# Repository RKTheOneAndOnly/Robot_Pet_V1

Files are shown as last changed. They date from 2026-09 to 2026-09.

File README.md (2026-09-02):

#  Robot Pet - v1: An ESP32-CAM Face-Tracking Companion

A desktop robot pet built around a single **AI-Thinker ESP32-CAM**. It streams video to a laptop, finds a face (or any coloured object you show it), and turns its head to follow you — while an OLED display gives it a pair of animated eyes that blink, glance around, and change mood.

<p align="center">
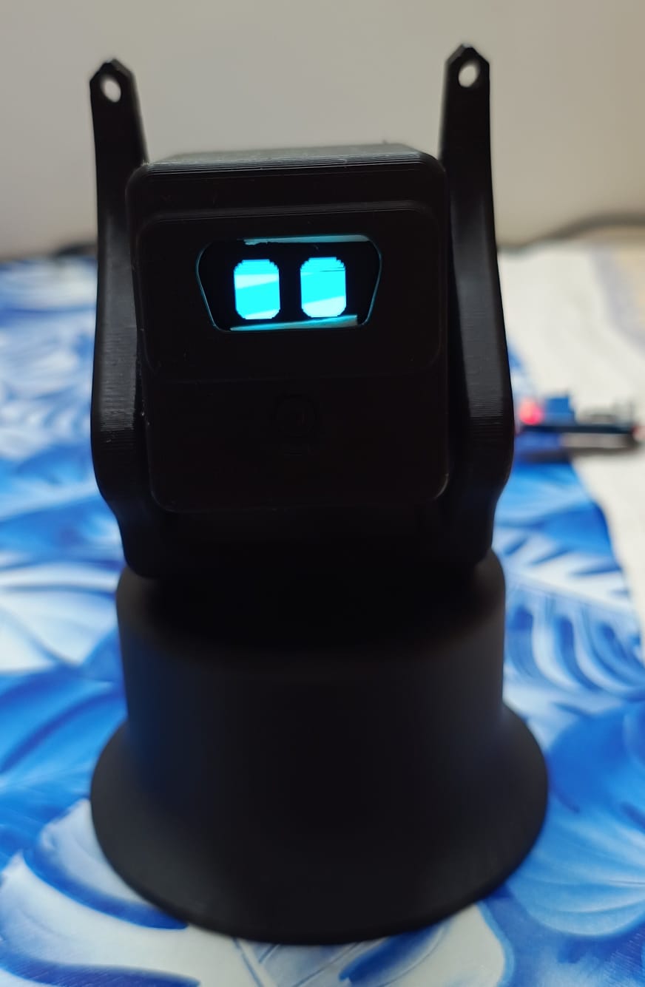
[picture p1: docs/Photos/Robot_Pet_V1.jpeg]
Robot Pet CAD - isometric view
    
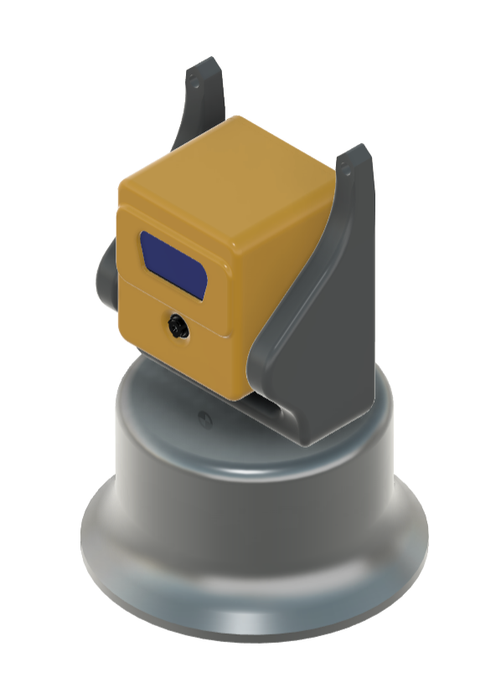
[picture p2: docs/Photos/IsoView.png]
Robot Pet CAD - isometric view
    
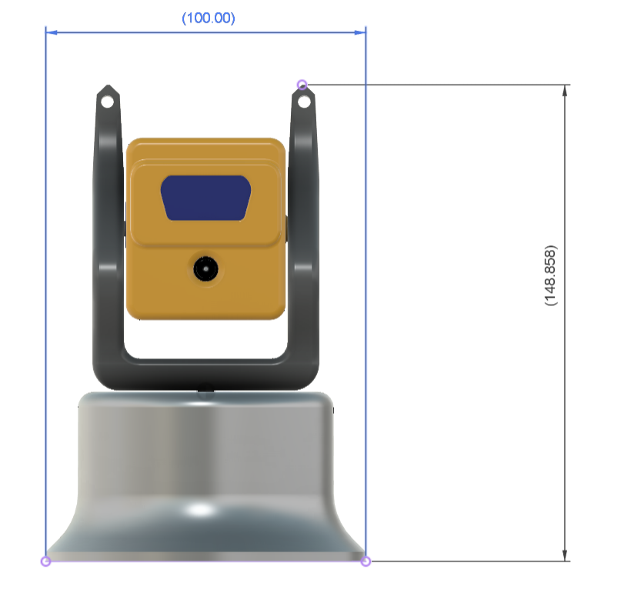
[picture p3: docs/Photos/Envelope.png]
Robot Pet motion envelope
    
</p>

The whole robot runs on one ESP32-CAM: camera, two servos, and an I²C display, with the vision work offloaded to a laptop over plain HTTP.

## 🔁 My Other Robotics Projects

- 🔗 [**Kai (ಕೈ) — 5 DOF Robotic Arm**](https://github.com/RKTheOneAndOnly/5-DOF-Robot_Arm-RK)
- 🔗 [**Robotics-Arm-Project-V01** — 3 DOF arm](https://github.com/RKTheOneAndOnly/Robotics-Arm-Project-V01)

---
## Table of Contents

1. [Introduction](#1-introduction)
2. [Components Used](#2-components-used)
3. [How It Works](#3-how-it-works)
4. [Wiring & Pin Map](#4-wiring--pin-map)
5. [Build & Flash](#5-build--flash)
6. [Running the Tracker](#6-running-the-tracker)
7. [Tuning](#7-tuning)
8. [Future Plans](#8-future-plans)
9. [Repository Structure](#9-repository-structure)
10. [Credits & Acknowledgements](#10-credits--acknowledgements)

---
## 1. Introduction

This project builds a small companion robot that:

- Streams **MJPEG video over WiFi** from an ESP32-CAM
- Tracks a **face** (Haar cascade) or any **coloured object** (HSV blob — hold up an apple)
- Drives **pan and tilt servos** to keep the target centred in frame
- Shows **animated, mood-driven eyes** on a 128×64 I²C OLED
- Is fully 3D printable, using cheap and widely available parts

The split of responsibilities is deliberate: the ESP32 handles hardware and owns all servo angles and limits, while the laptop does the computer vision. Vision never sends an absolute angle - it only says *"turn this far, this way"* - so a bug in the Python code can never drive the head into its mechanical stops.

---
## 2. Components Used

| Component | Quantity | Notes |
|---|---|---|
| AI-Thinker ESP32-CAM (OV2640) | 1 | Main controller + camera |
| SG90 micro servo | 2 | Pan and tilt |
| 1.3 " I²C OLED, 128×64 | 1 | 1.3 inch I2C OLED Display Module 4pin Blue Color |
| USB-to-TTL adapter (FTDI/CP2102)  | 1 | Flashing only — the ESP32-CAM has no USB |
| 5V power supply, ≥1A | 1 | **Separate supply for the servos** |
| 3D printed parts | 5 | STEP files in [`/cad`](./cad) |
| Jumper wires, M2/M3 screws | – | Assembly hardware |

> ⚠️ **Do not power the servos from the ESP32-CAM's 5V/3.3V pin.** Two SG90s under load will brown out the onboard regulator and reset the board mid-stream.

---
## 3. How It Works

```
   ESP32-CAM                                          Laptop (Python)
  ┌──────────────────────────────┐                  ┌──────────────────────────┐
  │  httpd :81  /stream  ────────┼── MJPEG ────────►│  reader                  │
  │  httpd :80  /control ◄───────┼── HTTP GET ──────┼─ sender                  │
  │                              │                  │                          │
  │  Display Controll            │                  │  detect using Open CV    │
  │  servos Controll             │                  └──────────────────────────┘
  └──────────────────────────────┘
```

**On the ESP32** - two independent `esp_http_server` instances, matching the layout of the Espressif `CameraWebServer` example. Port 81 serves the MJPEG stream; port 80 answers control requests. They *must* be separate servers: an httpd instance handles one request at a time, and the stream handler never returns while a viewer is connected, so a shared server would never answer a control request.

**On the laptop** - one thread reads the MJPEG stream and keeps only the newest frame, throwing away any backlog. The main loop decodes that frame, runs detection, smooths the target centroid, and computes a proportional step. A third thread issues the control request, so waiting for the ESP32 to reply never stalls tracking.

---
## 4. Wiring & Pin Map

The camera occupies almost every usable GPIO on this board — **including GPIO21/22**, the "default" ESP32 I²C pins. The OLED therefore cannot use them. These are the pins left over:

| Signal | GPIO | Notes |
|---|---|---|
| Pan servo | 2 | Strapping pin |
| Tilt servo | 13 | |
| OLED SDA | 14 | |
| OLED SCL | 15 | |

### Power

```
   5V supply ──┬── servo V+  (both servos)
               └── ESP32-CAM 5V

   GND ────────┬── servo GND (both servos)
               ├── ESP32-CAM GND      ← common ground is essential
               └── OLED GND
```

> 🔧 A loose common ground was the single hardest fault to find in this build. The servos simply do not move, the code looks wrong, and everything else keeps working perfectly. Check it first.

---
## 5. Build & Flash

Built with [PlatformIO](https://platformio.org/).

**1. Add your WiFi credentials** :

```bash
# edit include/wifi_config.h and set WIFI_SSID / WIFI_PASSWORD
```

**2. Flash the firmware**:

```bash
pio run -e esp32cam -t upload
```

> ✔️ If everything goes right the OLED shows the board's IP address once it joins WiFi.

**3. Check the camera** by opening `http://<esp32-ip>:81/stream` in a browser. This path is completely independent of the Python code, so it cleanly separates a camera/WiFi problem from a client problem.

### Servo bring-up test

A second environment builds a standalone sweep test — no camera, no WiFi, no display. Both servos sweep continuously so you can confirm the hardware works before blaming the software:

```bash
pio run -e servo_test -t upload
```

The onboard flash LED (GPIO4) blinks fast while sweeping up and slow while sweeping down, so you can confirm the sketch is running without a serial monitor attached. 
> ⚙️ **LED blinking but servos still?** That's power or wiring problem.

> Every SG90 has slightly different pulse-width endpoints. Centre both servos before assembling the head:

---
## 6. Running the Tracker

```bash
cd code/python
pip install -r requirements.txt

python track.py <esp32-ip>              # face tracking
python track.py <esp32-ip> color        # colour-blob tracking
```

| Key / action | Effect |
|---|---|
| `f` | Face mode (Haar cascade) |
| `c` | Colour mode (HSV blob) |
| **click the video** | Sample the colour under the cursor and track it |
| `q` | Quit |

>🤖 Colour mode is the easy way to test: hold up an apple, click it, and the robot follows it
---
## 7. Tuning

All tuning constants live at the top of [`code/python/track.py`](./code/python/track.py) — no reflashing needed.

| Constant | Default | Effect |
|---|---|---|
| `DEADZONE_PX` | 30 | Ignore errors smaller than this. Raise it if the head twitches on a still target. |
| `KP` | 10 | Degrees of servo movement per pixel of error. |
| `MAX_STEP_DEG` | 4 | Ceiling on any single move. |
| `SMOOTHING` | 0.5 | Centroid smoothing. 0 = raw and jumpy, 0.9 = heavy and laggy. |
| `SEND_INTERVAL_S`  | 0.08 | Minimum gap between movement commands. |
| `MOOD_INTERVAL_S`  | 2.0 | Minimum gap between mood updates; doubles as a keepalive. |
| `DETECT_WIDTH` | 300 | Detection runs on a copy scaled to this width. |

> Setting `USE_SLIDERS = True` brings a live OpenCV trackbar window for all of the above plus the HSV thresholds.

---
## 8. Future Plans

- Add a microphone and simple sound reactions
- Battery power and a mobile base
- AI based pet controll

---
## 9. Repository Structure

```bash
├── code/
│   ├── include/
│   │   └── wifi_config.h            # Edit wifi credentials
│   ├── python/
│   │   ├── calibrate_servos.py      # centre the servos before assembly
│   │   ├── track.py                 # face / colour tracker
│   │   └── requirements.txt
│   ├── src/
│   │   ├── main.cpp                 # full firmware
│   │   └── servo_test.cpp           # standalone servo bring-up test
│   └── platformio.ini
├── cad/                             # STEP files for the printed parts
├── docs/
│   └── Photos /
│   └── Videos/
├── LICENSE
└── README.md
```

---
## 10. Credits & Acknowledgements

Special thanks to:
- The open-source robotics community, for the abundance of shared knowledge and tools.

> *Crafted with ❤️, driven by curiosity, and fueled by innovation.*

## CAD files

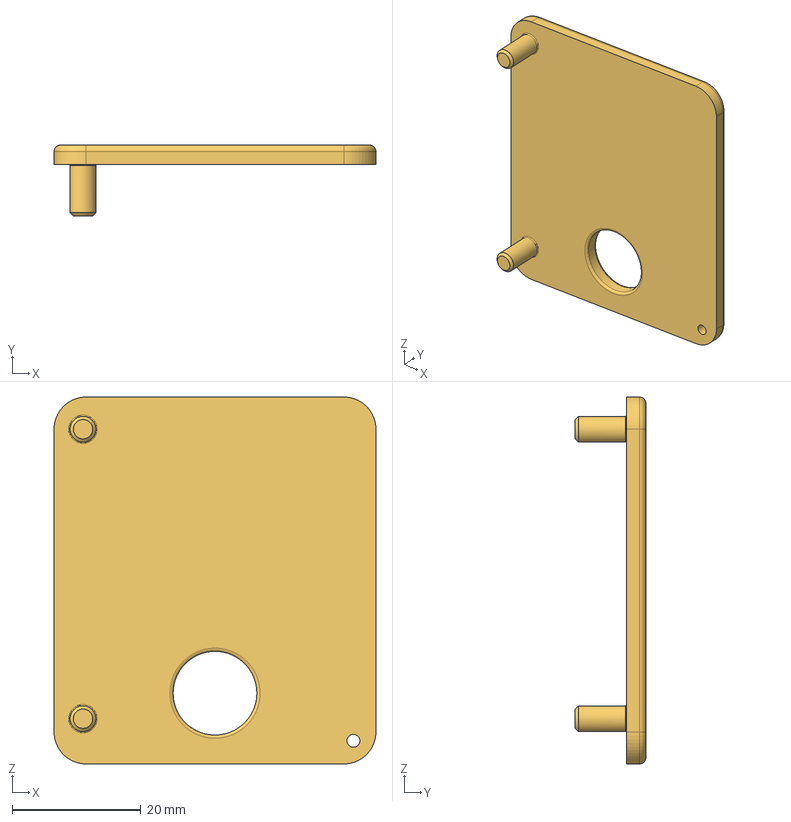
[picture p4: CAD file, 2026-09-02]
cad/Cover.step
50.0 x 11.0 x 57.0 mm

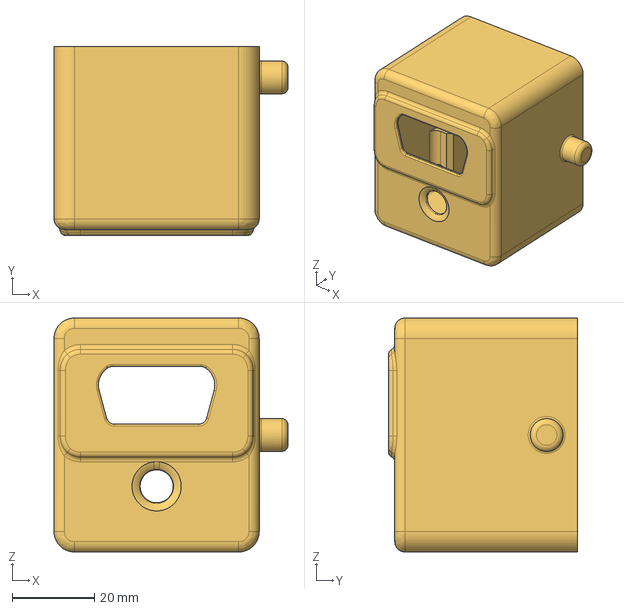
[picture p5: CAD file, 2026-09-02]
cad/Head.step
57.0 x 46.0 x 57.0 mm

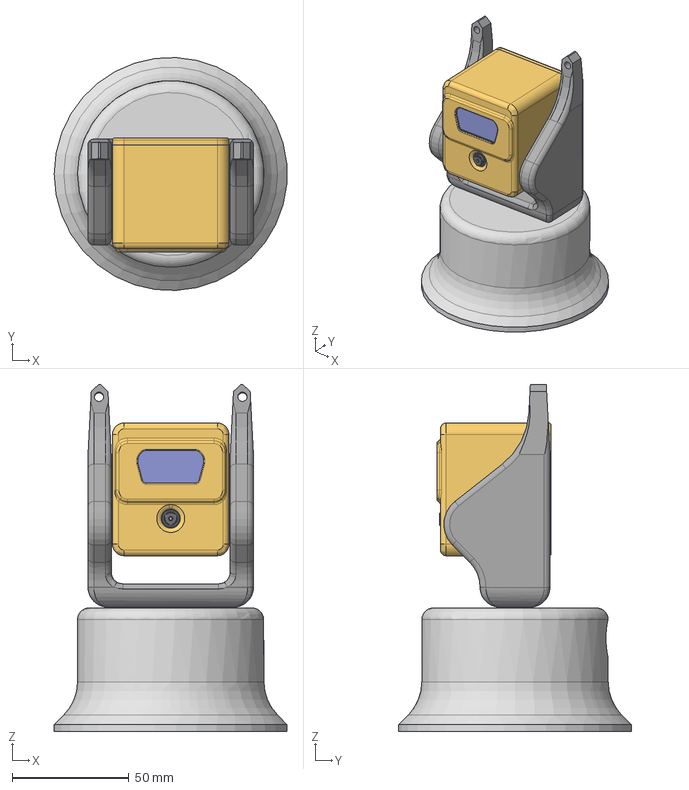
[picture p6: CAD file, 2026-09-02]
cad/Robot_pet_v2.step
99.8 x 99.9 x 148.9 mm
Board
PIN HEADER MALE 2.54MM P4
LCD
FLEX FILM
4 lü Lehim
PIN HEADER FAMALE 2.54MM P4
ESP3-CAM
Head
Tower Pro - Micro Servo 9g - SG90.1 x 2
SG90 - Micro Servo 9g - Tower Pro.3 x 2
Holder
Cover
base

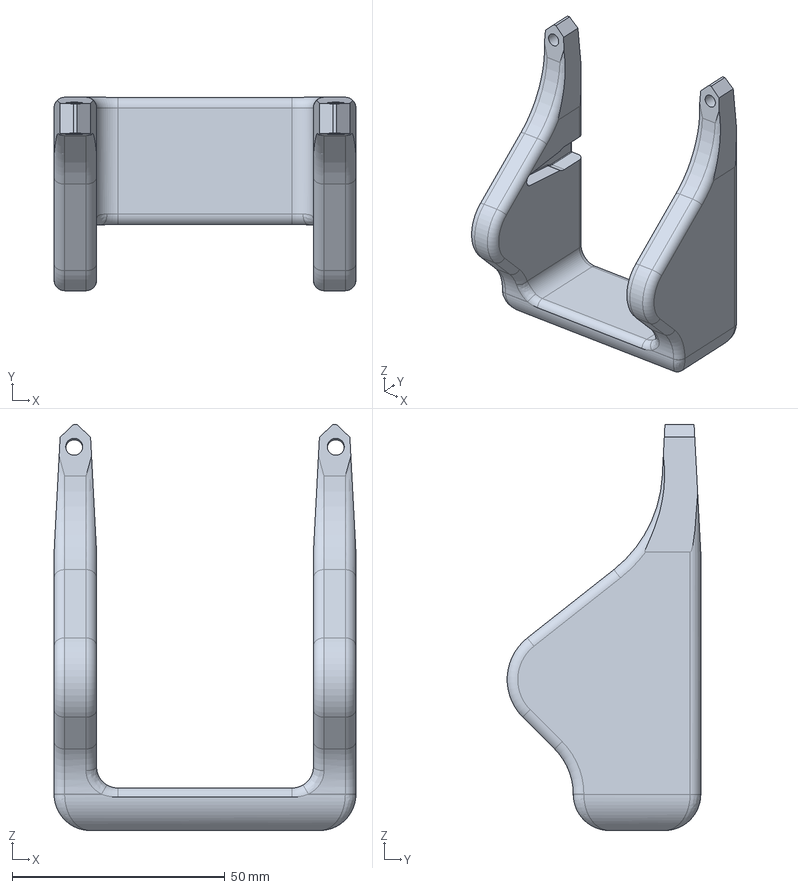
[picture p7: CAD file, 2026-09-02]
cad/Holder.step
71.0 x 45.5 x 95.5 mm

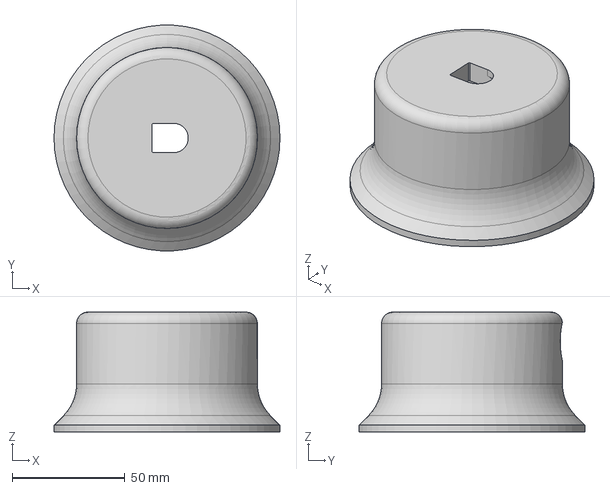
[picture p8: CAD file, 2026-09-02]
cad/base.step
100.0 x 99.9 x 53.0 mm

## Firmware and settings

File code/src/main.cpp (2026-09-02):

#include <Arduino.h>
#include "soc/soc.h"
#include "soc/rtc_cntl_reg.h"
#include <WiFi.h>
#include "esp_camera.h"
#include "esp_http_server.h"
#include "esp_system.h"
#include <ESP32Servo.h>
#include <Wire.h>
#include <U8g2lib.h>
#include "wifi_config.h"


#define PWDN_GPIO_NUM 32
#define RESET_GPIO_NUM -1
#define XCLK_GPIO_NUM 0
#define SIOD_GPIO_NUM 26
#define SIOC_GPIO_NUM 27
#define Y9_GPIO_NUM 35
#define Y8_GPIO_NUM 34
#define Y7_GPIO_NUM 39
#define Y6_GPIO_NUM 36
#define Y5_GPIO_NUM 21
#define Y4_GPIO_NUM 19
#define Y3_GPIO_NUM 18
#define Y2_GPIO_NUM 5
#define VSYNC_GPIO_NUM 25
#define HREF_GPIO_NUM 23
#define PCLK_GPIO_NUM 22

// ---------------------------------------------------------------------------
// Transport: two esp_http_server instances
//
//   Port 80 (CONTROL_PORT) - GET /control?pan=1&tilt=-1&mood=happy
//   Port 81 (STREAM_PORT)  - GET /stream, multipart MJPEG
//
// A single httpd instance serves one request at a time, 
// and the stream handler never returns while a viewer is
// watching. A single server would therefore never answer a control request.
// The reference splits them for exactly this reason, and gives each its own
// ctrl_port as well.
// ---------------------------------------------------------------------------
httpd_handle_t streamHttpd = NULL;
httpd_handle_t controlHttpd = NULL;

Servo panServo;
Servo tiltServo;
int currentPan = SERVO_PAN_CENTER_ANGLE;
int currentTilt = SERVO_TILT_CENTER_ANGLE;

U8G2_SH1106_128X64_NONAME_F_HW_I2C u8g2(U8G2_R0, /* reset=*/ U8X8_PIN_NONE);

// ---------------------------------------------------------------------------
// Servo output
// ---------------------------------------------------------------------------
volatile int targetPan = SERVO_PAN_CENTER_ANGLE;
volatile int targetTilt = SERVO_TILT_CENTER_ANGLE;

// Last commanded position, kept in RTC memory so it survives a reset.

#define SERVO_POS_MAGIC 0x5E70A1u
RTC_NOINIT_ATTR uint32_t servoPosMagic;
RTC_NOINIT_ATTR int lastPanPos;
RTC_NOINIT_ATTR int lastTiltPos;

// Relative commands accumulate against the TARGET, never against the actual position.
void setPanTarget(int angle) {
  targetPan = constrain(angle, SERVO_PAN_MIN_ANGLE, SERVO_PAN_MAX_ANGLE);
}

void setTiltTarget(int angle) {
  targetTilt = constrain(angle, SERVO_TILT_MIN_ANGLE, SERVO_TILT_MAX_ANGLE);
}

void writePan(int angle) {
  currentPan = angle;
  lastPanPos = angle; // remembered across a reset - see SERVO_POS_MAGIC above
  panServo.write(SERVO_PAN_INVERT ? (180 - angle) : angle);
}

void writeTilt(int angle) {
  currentTilt = angle;
  lastTiltPos = angle;
  tiltServo.write(SERVO_TILT_INVERT ? (180 - angle) : angle);
}

// Walks each axis toward its target a small step at a time. See the slewrate notes in wifi_config.h
void servoTask(void *pvParameters) {
  bool panGoesFirst = true;

  for (;;) {
    int wantPan = targetPan;
    int wantTilt = targetTilt;
    bool panNeeds = (currentPan != wantPan);
    bool tiltNeeds = (currentTilt != wantTilt);

    if (panNeeds && tiltNeeds) {
      if (panGoesFirst) {
        tiltNeeds = false;
      } else {
        panNeeds = false;
      }
      panGoesFirst = !panGoesFirst;
    }

    if (panNeeds) {
      int delta = constrain(wantPan - currentPan,
                            -SERVO_SLEW_DEG_PER_STEP, SERVO_SLEW_DEG_PER_STEP);
      writePan(currentPan + delta);
    }
    if (tiltNeeds) {
      int delta = constrain(wantTilt - currentTilt,
                            -SERVO_SLEW_DEG_PER_STEP, SERVO_SLEW_DEG_PER_STEP);
      writeTilt(currentTilt + delta);
    }

    vTaskDelay(pdMS_TO_TICKS(SERVO_SLEW_TICK_MS));
  }
}

// ---------------------------------------------------------------------------
// Mood-driven animated eyes (in the spirit of playfultechnology/esp32-eyes).
//
// Runs entirely inside eyesTask on its own core.
// ---------------------------------------------------------------------------
enum Mood {
  MOOD_NEUTRAL,
  MOOD_HAPPY,
  MOOD_CURIOUS,
  MOOD_ANGRY,
  MOOD_SLEEPY,
  MOOD_SURPRISED,
  MOOD_LOVE,
  MOOD_SAD,
  MOOD_SUSPICIOUS,
  MOOD_DIZZY,
  MOOD_WINK,
  MOOD_BORED,
  MOOD_EXCITED,
  MOOD_COUNT // keep last - number of moods, used for range checks
};

volatile int requestedMood = MOOD_NEUTRAL;
volatile int gazeHintX = 0; 
volatile int gazeHintY = 0;
volatile unsigned long lastCommandMillis = 0;

const unsigned long TRACKING_TIMEOUT_MS = 1500;
const unsigned long SLEEPY_TIMEOUT_MS = 60000; 

const int screenWidth = 128;
const int screenHeight = 64;
const int eyeWidth = 30;
const int eyeHeight = 40;
const int eyeGap = 16;
const int eyeCenterY = screenHeight / 2;
const int leftEyeCX = screenWidth / 2 - (eyeGap / 2 + eyeWidth / 2);
const int rightEyeCX = screenWidth / 2 + (eyeGap / 2 + eyeWidth / 2);


const char *const MOOD_NAMES[] = {
  "neutral", "happy", "curious", "angry", "sleepy", "surprised",
  "love", "sad", "suspicious", "dizzy", "wink", "bored", "excited"
};

static_assert(sizeof(MOOD_NAMES) / sizeof(MOOD_NAMES[0]) == MOOD_COUNT,
              "MOOD_NAMES must list every Mood, in enum order");

int moodFromName(const char *name) {
  for (int i = 0; i < MOOD_COUNT; i++) {
    if (!strcmp(name, MOOD_NAMES[i])) return i;
  }
  return MOOD_NEUTRAL; 
}

struct MoodStyle {
  float openScale;
  float widthScale;
  int yOffset;
  int blinkMinMs;
  int blinkMaxMs;
};

MoodStyle styleFor(Mood m) {
  switch (m) {
    case MOOD_HAPPY:      return {0.85f, 1.00f,  2, 2500, 5000};
    case MOOD_CURIOUS:    return {1.00f, 1.00f, -2, 1800, 3800};
    case MOOD_ANGRY:      return {0.75f, 1.00f,  0, 3000, 6000};
    case MOOD_SLEEPY:     return {0.30f, 1.00f,  6, 4000, 8000};
    case MOOD_SURPRISED:  return {1.15f, 0.85f, -2, 3500, 7000};
    // Hearts are drawn as a shape, so the lid opening just controls size.
    case MOOD_LOVE:       return {1.05f, 1.00f,  0, 2800, 5200};
    case MOOD_SAD:        return {0.80f, 1.00f,  3, 3200, 6000};
    // Narrow AND wide, so it does not read as merely sleepy.
    case MOOD_SUSPICIOUS: return {0.22f, 1.15f,  0, 3000, 7000};
    case MOOD_DIZZY:      return {1.00f, 1.00f,  0, 5000, 9000};
    case MOOD_WINK:       return {0.95f, 1.00f,  0, 2500, 5000};
    case MOOD_BORED:      return {0.45f, 1.00f,  4, 3500, 7000};
    // Starstruck: drawn as a shape, and blinks rarely so the sparkle shows.
    case MOOD_EXCITED:    return {1.10f, 1.00f, -1, 4000, 8000};
    default:              return {1.00f, 1.00f,  0, 2500, 6000};
  }
}

float animOpen = 1.0f;
float animGazeX = 0.0f;
float animGazeY = 0.0f;
float gazeTargetX = 0.0f;
float gazeTargetY = 0.0f;
int blinkPhase = 0; 
unsigned long blinkPhaseEnd = 0;
unsigned long nextBlinkAt = 0;
unsigned long nextSaccadeAt = 0;
uint32_t lastRenderKey = 0xFFFFFFFF;

void drawEye(int cx, int cy, int w, int h, Mood m, bool isLeft) {
  h = constrain(h, 0, 60);
  if (w < 4) return;

  if (h < 5) { // lids effectively shut - just a lash line
    u8g2.drawBox(cx - w / 2, cy - 1, w, 3);
    return;
  }

  if (m == MOOD_HAPPY) {
    int baseline = cy + h / 2;
    int x0 = cx - w / 2;
    for (int i = 0; i < w; i++) {
      float t = (float)(i - w / 2) / (w / 2.0f); // -1 .. 1
      int top = baseline - (int)(h * (1.0f - t * t));
      if (top < baseline) u8g2.drawVLine(x0 + i, top, baseline - top);
    }
    return;
  }

  if (m == MOOD_LOVE) {
    int r = max(3, w / 4);
    int lobeY = cy - h / 8;
    u8g2.drawDisc(cx - r, lobeY, r, U8G2_DRAW_ALL);
    u8g2.drawDisc(cx + r, lobeY, r, U8G2_DRAW_ALL);
    u8g2.drawTriangle(cx - 2 * r, lobeY, cx + 2 * r, lobeY, cx, cy + h / 2);
    return;
  }

  if (m == MOOD_EXCITED) {
    int hx = w / 2, hy = h / 2;
    int wx = max(2, w / 6), wy = max(2, h / 6);
    u8g2.drawTriangle(cx, cy - hy, cx - wx, cy, cx + wx, cy); // up
    u8g2.drawTriangle(cx, cy + hy, cx - wx, cy, cx + wx, cy); // down
    u8g2.drawTriangle(cx - hx, cy, cx, cy - wy, cx, cy + wy); // left
    u8g2.drawTriangle(cx + hx, cy, cx, cy - wy, cx, cy + wy); // right
    return;
  }

  if (m == MOOD_DIZZY) {
    int r = min(w, h) / 2;
    for (int o = 0; o <= 1; o++) {
      u8g2.drawLine(cx - r, cy - r + o, cx + r, cy + r + o);
      u8g2.drawLine(cx - r, cy + r + o, cx + r, cy - r + o);
    }
    return;
  }

  if (m == MOOD_WINK && !isLeft) {
    u8g2.drawBox(cx - w / 2, cy - 1, w, 3);
    return;
  }

  int x = cx - w / 2;
  int y = cy - h / 2;
  int r = min(8, min(w, h) / 2);
  u8g2.drawRBox(x, y, w, h, r);

  if (m == MOOD_ANGRY) {
    u8g2.setDrawColor(0);
    if (isLeft) {
      u8g2.drawTriangle(x + w + 1, y - 1, x + w + 1, y + h / 2, x - 1, y - 1);
    } else {
      u8g2.drawTriangle(x - 1, y - 1, x - 1, y + h / 2, x + w + 1, y - 1);
    }
    u8g2.setDrawColor(1);
  } else if (m == MOOD_SAD) {
    u8g2.setDrawColor(0);
    if (isLeft) {
      u8g2.drawTriangle(x - 1, y - 1, x - 1, y + h / 2, x + w + 1, y - 1);
    } else {
      u8g2.drawTriangle(x + w + 1, y - 1, x + w + 1, y + h / 2, x - 1, y - 1);
    }
    u8g2.setDrawColor(1);
  } else if (m == MOOD_SURPRISED && w > 14 && h > 14) {
    u8g2.setDrawColor(0);
    u8g2.drawRBox(x + 5, y + 5, w - 10, h - 10, max(2, r - 3));
    u8g2.setDrawColor(1);
  } else if (m == MOOD_BORED && h > 6) {
    u8g2.setDrawColor(0);
    u8g2.drawBox(x - 1, y - 1, w + 2, h / 3);
    u8g2.setDrawColor(1);
  }
}

void renderFace(Mood m, float open, float gx, float gy) {
  MoodStyle st = styleFor(m);
  int w = (int)(eyeWidth * st.widthScale);
  int h = (int)(eyeHeight * open);
  int cy = eyeCenterY + st.yOffset + (int)gy;
  int lx = leftEyeCX + (int)gx;
  int rx = rightEyeCX + (int)gx;

  u8g2.clearBuffer();
  if (m == MOOD_CURIOUS) {
    drawEye(lx, cy - 2, w, (int)(h * 1.12f), m, true);
    drawEye(rx, cy + 2, w, (int)(h * 0.88f), m, false);
  } else {
    drawEye(lx, cy, w, h, m, true);
    drawEye(rx, cy, w, h, m, false);
  }
  u8g2.sendBuffer();
}

void updateEyes() {
  unsigned long now = millis();
  unsigned long sinceCommand = now - lastCommandMillis;

  Mood m = (Mood)requestedMood;
  if (sinceCommand > SLEEPY_TIMEOUT_MS) m = MOOD_SLEEPY;
  MoodStyle st = styleFor(m);

  if (blinkPhase == 0) {
    if ((long)(now - nextBlinkAt) >= 0) {
      blinkPhase = 1;
      blinkPhaseEnd = now + 90;
    }
  } else if ((long)(now - blinkPhaseEnd) >= 0) {
    if (blinkPhase == 1) {
      blinkPhase = 2;
      blinkPhaseEnd = now + 130;
    } else {
      blinkPhase = 0;
      nextBlinkAt = now + random(st.blinkMinMs, st.blinkMaxMs);
    }
  }
  float openTarget = (blinkPhase == 1) ? 0.0f : st.openScale;

  if (sinceCommand < TRACKING_TIMEOUT_MS) {
    gazeTargetX = gazeHintX * 5.0f;
    gazeTargetY = gazeHintY * 3.0f;
    nextSaccadeAt = now + 900;
  } else if ((long)(now - nextSaccadeAt) >= 0) {
    gazeTargetX = (float)random(-6, 7);
    gazeTargetY = (float)random(-3, 4);
    nextSaccadeAt = now + random(1500, 4000);
  }

  animOpen += (openTarget - animOpen) * 0.35f;
  animGazeX += (gazeTargetX - animGazeX) * 0.20f;
  animGazeY += (gazeTargetY - animGazeY) * 0.20f;

  uint32_t key = ((uint32_t)(animOpen * 40.0f) << 20) ^
                 ((uint32_t)(animGazeX + 32.0f) << 12) ^
                 ((uint32_t)(animGazeY + 32.0f) << 4) ^
                 (uint32_t)m;
  if (key == lastRenderKey) return;
  lastRenderKey = key;

  renderFace(m, animOpen, animGazeX, animGazeY);
}

void eyesTask(void *pvParameters) {
  for (;;) {
    updateEyes();
    vTaskDelay(pdMS_TO_TICKS(40)); // ~25fps, about the most 400kHz I2C sustains
  }
}

// ---------------------------------------------------------------------------
// Why did we last reboot?
//
// With no serial attached during normal running, the OLED is the only place
// this can be reported
//
//   POWERON   - the rail actually collapsed. Servo inrush pulling the supply
//               down is the usual cause on this build.
//   BROWNOUT  - the detector fired, i.e. the disable in setup() is not taking
//               effect (it is armed before setup() runs).
//   PANIC     - a software crash, NOT power. A task stack overflow looks like
//               this, and would be pure coincidence with servo movement.
//   TASK WDT  - a task hogged its core without yielding.
//   SW        - our own ESP.restart(), e.g. the camera retry path below.
// ---------------------------------------------------------------------------
const char *resetReasonName(esp_reset_reason_t reason) {
  switch (reason) {
    case ESP_RST_POWERON:   return "POWERON-rail died";
    case ESP_RST_BROWNOUT:  return "BROWNOUT";
    case ESP_RST_PANIC:     return "PANIC-crash!";
    case ESP_RST_TASK_WDT:  return "TASK WDT";
    case ESP_RST_INT_WDT:   return "INT WDT";
    case ESP_RST_WDT:       return "WDT";
    case ESP_RST_SW:        return "SW restart";
    case ESP_RST_EXT:       return "EXT reset pin";
    case ESP_RST_DEEPSLEEP: return "deep sleep";
    default:                return "unknown";
  }
}

void showStatus(const char *line1, const char *line2) {
  u8g2.clearBuffer();
  u8g2.setFont(u8g2_font_6x10_tr);
  u8g2.drawStr(0, 12, line1);
  u8g2.drawStr(0, 26, line2);
  u8g2.sendBuffer();
}

// How many times camera bring-up is retried before giving up and rebooting.
const int CAMERA_INIT_ATTEMPTS = 4;

#define CAM_FAIL_MAGIC 0xC0FFEEu
const uint32_t CAMERA_MAX_FAIL_REBOOTS = 3;
RTC_NOINIT_ATTR uint32_t camFailMagic;
RTC_NOINIT_ATTR uint32_t camFailCount;

esp_err_t initCamera(uint32_t xclkHz) {
  camera_config_t config = {};
  config.ledc_channel = LEDC_CHANNEL_0;
  config.ledc_timer = LEDC_TIMER_0;
  config.pin_d0 = Y2_GPIO_NUM;
  config.pin_d1 = Y3_GPIO_NUM;
  config.pin_d2 = Y4_GPIO_NUM;
  config.pin_d3 = Y5_GPIO_NUM;
  config.pin_d4 = Y6_GPIO_NUM;
  config.pin_d5 = Y7_GPIO_NUM;
  config.pin_d6 = Y8_GPIO_NUM;
  config.pin_d7 = Y9_GPIO_NUM;
  config.pin_xclk = XCLK_GPIO_NUM;
  config.pin_pclk = PCLK_GPIO_NUM;
  config.pin_vsync = VSYNC_GPIO_NUM;
  config.pin_href = HREF_GPIO_NUM;
  config.pin_sscb_sda = SIOD_GPIO_NUM;
  config.pin_sscb_scl = SIOC_GPIO_NUM;
  config.pin_pwdn = PWDN_GPIO_NUM;
  config.pin_reset = RESET_GPIO_NUM;
  config.xclk_freq_hz = xclkHz;
  config.pixel_format = PIXFORMAT_JPEG;
  config.frame_size = FRAMESIZE_QVGA;
  config.jpeg_quality = 12;

  if (psramFound()) {
    config.fb_count = 2;
    config.fb_location = CAMERA_FB_IN_PSRAM;
    config.grab_mode = CAMERA_GRAB_LATEST;
  } else {
    config.fb_count = 1;
    config.fb_location = CAMERA_FB_IN_DRAM;
    config.grab_mode = CAMERA_GRAB_WHEN_EMPTY;
  }

  return esp_camera_init(&config);
}

// ---------------------------------------------------------------------------
// Camera bring-up, with retries.
//
//   0x105  ESP_ERR_NOT_FOUND     - sensor not detected. Power rail sagging at
//                                  boot, or a loose camera ribbon connector.
//   0x101  ESP_ERR_NO_MEM        - out of memory / PSRAM not found.
//   0x103  ESP_ERR_INVALID_STATE - already initialised.
// ---------------------------------------------------------------------------
esp_err_t bringUpCamera() {
  esp_err_t err = ESP_FAIL;

  for (int attempt = 1; attempt <= CAMERA_INIT_ATTEMPTS; attempt++) {
    bool slowClock = (attempt == CAMERA_INIT_ATTEMPTS);
    uint32_t xclk = slowClock ? 10000000 : 20000000;

    err = initCamera(xclk);
    if (err == ESP_OK) {
      Serial.printf("Camera up on attempt %d (xclk %u Hz)\n", attempt, xclk);
      if (slowClock) {
        showStatus("Camera OK - SLOW", "xclk 10MHz, low fps");
        delay(2500);
      }
      return ESP_OK;
    }

    Serial.printf("Camera init failed: 0x%x (attempt %d/%d, xclk %u Hz)\n",
                  err, attempt, CAMERA_INIT_ATTEMPTS, xclk);

    char detail[24];
    snprintf(detail, sizeof(detail), "0x%x  try %d/%d",
             err, attempt, CAMERA_INIT_ATTEMPTS);
    showStatus("Camera init FAILED", detail);
    esp_camera_deinit();
    delay(600);
  }
  return err;
}

// ---------------------------------------------------------------------------
// MJPEG stream server (port 80, GET /stream)
// ---------------------------------------------------------------------------
#define PART_BOUNDARY "123456789000000000000987654321"
static const char *STREAM_CONTENT_TYPE = "multipart/x-mixed-replace;boundary=" PART_BOUNDARY;
static const char *STREAM_BOUNDARY = "\r\n--" PART_BOUNDARY "\r\n";
static const char *STREAM_PART = "Content-Type: image/jpeg\r\nContent-Length: %u\r\n\r\n";

esp_err_t streamHandler(httpd_req_t *req) {
  esp_err_t res = httpd_resp_set_type(req, STREAM_CONTENT_TYPE);
  if (res != ESP_OK) return res;
  httpd_resp_set_hdr(req, "Access-Control-Allow-Origin", "*");

  Serial.println("Stream client connected");
  char partBuf[64];

  while (true) {
    camera_fb_t *fb = esp_camera_fb_get();
    if (!fb) {
      res = ESP_FAIL;
      break;
    }
    if (fb->format != PIXFORMAT_JPEG) {
      esp_camera_fb_return(fb);
      res = ESP_FAIL;
      break;
    }

    size_t hlen = snprintf(partBuf, sizeof(partBuf), STREAM_PART, fb->len);
    res = httpd_resp_send_chunk(req, partBuf, hlen);
    if (res == ESP_OK) res = httpd_resp_send_chunk(req, (const char *)fb->buf, fb->len);
    if (res == ESP_OK) res = httpd_resp_send_chunk(req, STREAM_BOUNDARY, strlen(STREAM_BOUNDARY));
    esp_camera_fb_return(fb);

    if (res != ESP_OK) break;

  }

  Serial.println("Stream client disconnected");
  return res;
}

// ---------------------------------------------------------------------------
esp_err_t controlHandler(httpd_req_t *req) {
  char query[160];
  char val[24];

  if (httpd_req_get_url_query_str(req, query, sizeof(query)) == ESP_OK) {
    if (httpd_query_key_value(query, "pan", val, sizeof(val)) == ESP_OK) {
      int delta = atoi(val);
      if (delta != 0) {
        setPanTarget(targetPan + delta);
        gazeHintX = (delta > 0) ? 1 : -1;
      }
    }
    if (httpd_query_key_value(query, "tilt", val, sizeof(val)) == ESP_OK) {
      int delta = atoi(val);
      if (delta != 0) {
        setTiltTarget(targetTilt + delta);
        gazeHintY = (delta > 0) ? 1 : -1;
      }
    }
    if (httpd_query_key_value(query, "panabs", val, sizeof(val)) == ESP_OK) {
      setPanTarget(atoi(val));
    }
    if (httpd_query_key_value(query, "tiltabs", val, sizeof(val)) == ESP_OK) {
      setTiltTarget(atoi(val));
    }
    if (httpd_query_key_value(query, "mood", val, sizeof(val)) == ESP_OK) {
      requestedMood = moodFromName(val);
    }
    lastCommandMillis = millis();
  }

  httpd_resp_set_hdr(req, "Access-Control-Allow-Origin", "*");
  return httpd_resp_send(req, "ok", 2);
}

void startServers() {
  httpd_config_t streamConfig = HTTPD_DEFAULT_CONFIG();
  streamConfig.server_port = STREAM_PORT;
  streamConfig.ctrl_port = 32769;
  streamConfig.max_uri_handlers = 2;
  streamConfig.lru_purge_enable = true;

  httpd_uri_t streamUri = {};
  streamUri.uri = "/stream";
  streamUri.method = HTTP_GET;
  streamUri.handler = streamHandler;
  streamUri.user_ctx = NULL;

  if (httpd_start(&streamHttpd, &streamConfig) == ESP_OK) {
    httpd_register_uri_handler(streamHttpd, &streamUri);
    Serial.printf("MJPEG stream server on port %d (/stream)\n", STREAM_PORT);
  } else {
    Serial.println("Failed to start MJPEG stream server");
  }

  httpd_config_t controlConfig = HTTPD_DEFAULT_CONFIG();
  controlConfig.server_port = CONTROL_PORT;
  controlConfig.ctrl_port = 32768;
  controlConfig.max_uri_handlers = 4;
  controlConfig.lru_purge_enable = true;

  httpd_uri_t controlUri = {};
  controlUri.uri = "/control";
  controlUri.method = HTTP_GET;
  controlUri.handler = controlHandler;
  controlUri.user_ctx = NULL;

  if (httpd_start(&controlHttpd, &controlConfig) == ESP_OK) {
    httpd_register_uri_handler(controlHttpd, &controlUri);
    Serial.printf("Control server on port %d (/control)\n", CONTROL_PORT);
  } else {
    Serial.println("Failed to start control server");
  }
}
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
void loop() {
  delay(1000);
}

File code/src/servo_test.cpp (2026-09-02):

// Standalone servo bring-up test for the ESP32-CAM board - no camera, no
// WiFi, no display, no serial input needed. Both servos continuously sweep
// 0 -> 180 -> 0 so you can just watch them move. If they don't move here,
// it's power/wiring/pin, not a software/timer conflict with the camera.


// Run using & "$env:USERPROFILE\.platformio\penv\Scripts\pio.exe" run -e servo_test -t upload

#include <Arduino.h>
#include <ESP32Servo.h>
#include "wifi_config.h"

#define FLASH_LED_PIN 4

Servo panServo;
Servo tiltServo;

const int STEP_DEG = 1;
const int STEP_DELAY_MS = 15; // ~2.7s for a full 0->180 sweep

bool ledState = false;

void heartbeat(int blinkPeriodMs) {
  static unsigned long lastToggle = 0;
  unsigned long now = millis();
  if (now - lastToggle >= (unsigned long)blinkPeriodMs) {
    lastToggle = now;
    ledState = !ledState;
    digitalWrite(FLASH_LED_PIN, ledState);
  }
}

void setup() {
  pinMode(FLASH_LED_PIN, OUTPUT);
  Serial.begin(115200);
  delay(300);
  Serial.println("Servo sweep test: 0 -> 180 -> 0, no input needed.");

  for (int i = 0; i < 3; i++) {
    digitalWrite(FLASH_LED_PIN, HIGH);
    delay(200);
    digitalWrite(FLASH_LED_PIN, LOW);
    delay(200);
  }

  panServo.setPeriodHertz(50);
  tiltServo.setPeriodHertz(50);
  panServo.attach(SERVO_PAN_PIN, SERVO_PAN_MIN_PULSE_US, SERVO_PAN_MAX_PULSE_US);
  tiltServo.attach(SERVO_TILT_PIN, SERVO_TILT_MIN_PULSE_US, SERVO_TILT_MAX_PULSE_US);

  panServo.write(SERVO_PAN_MIN_ANGLE);
  tiltServo.write(SERVO_TILT_MIN_ANGLE);
  delay(500);
}

void loop() {
  for (int a = 0; a <= 180; a += STEP_DEG) {
    if (a >= SERVO_PAN_MIN_ANGLE && a <= SERVO_PAN_MAX_ANGLE) panServo.write(a);
    if (a >= SERVO_TILT_MIN_ANGLE && a <= SERVO_TILT_MAX_ANGLE) tiltServo.write(a);
    heartbeat(150);
    delay(STEP_DELAY_MS);
  }
  delay(400);
  for (int a = 180; a >= 0; a -= STEP_DEG) {
    if (a >= SERVO_PAN_MIN_ANGLE && a <= SERVO_PAN_MAX_ANGLE) panServo.write(a);
    if (a >= SERVO_TILT_MIN_ANGLE && a <= SERVO_TILT_MAX_ANGLE) tiltServo.write(a);
    heartbeat(500);
    delay(STEP_DELAY_MS);
  }
  delay(400);
}
